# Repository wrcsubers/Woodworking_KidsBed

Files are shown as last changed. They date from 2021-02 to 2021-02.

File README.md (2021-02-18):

# Woodworking Stuff: Kid's Bed Frame

This is a simple Twin sized bed frame made from dimensional lumber.  This bed frame is designed to be modular so it can be easily transformed into a bunk bed by using taller posts.  

Image of Completed Kids Bed Frame 1

Image of Completed Kids Bed Frame 2

Image of Completed Kids Bed Frame 3

I used an 8" Memory Foam mattress, and I wouldn't recommend anything taller than that as you lose side-rail height.  The height of the side rail is set at 12" to allow ample storage beneath the bed, my 2-1/2 year old son had no problem climbing in/out of bed himself at this height.

CAD Files are provided [here](https://github.com/wrcsubers/Woodworking_KidsBedFrame/tree/main/_CAD%20Files) if you want to change anything, or you can print the PDFs directly from [here](https://github.com/wrcsubers/Woodworking_KidsBedFrame/tree/main/_PDFs) =)

* Lumber sizes used:
  * (10) 2" x 2" x 96"
    * Vertical bars for headboard/footboard
    * Vertical and Horizontal bars for side rails
    * Support rails for slats
  * (1) 2" x 4" x 96"
    * Top rail for headboard/footboard
  * (3) 2" x 6" x 96"
    * Bottom rail for headboard/footboard and side rails
  * (2) 4" x 4" x 96"
    * Posts
  * (5) 1" x 3" x 96"
    * Bed slats

* Fasteners used:
  * (20) SPAX 1/4" x 4-1/2" Powerlag Hex Drive Washer Head Zinc Coated Lag Screw
  * 2" Wood Screws
  * 1-1/4" 18ga Brad Nails
  * Wood Glue

**This bed does not conform to the recommended sizes for bar spacing for toddlers/infants!  I felt comfortable using the sizes as specified, please determine on your own if these are suitable for you situation.**

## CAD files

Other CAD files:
_CAD Files/KidsBedFrame_SlatSpacingRail.dxf
_CAD Files/KidsBedFrame_HeadboardFootboard.dxf
_CAD Files/KidsBedFrame_RearSideRail.dxf
_CAD Files/KidsBedFrame_FrontSideRail.dxf

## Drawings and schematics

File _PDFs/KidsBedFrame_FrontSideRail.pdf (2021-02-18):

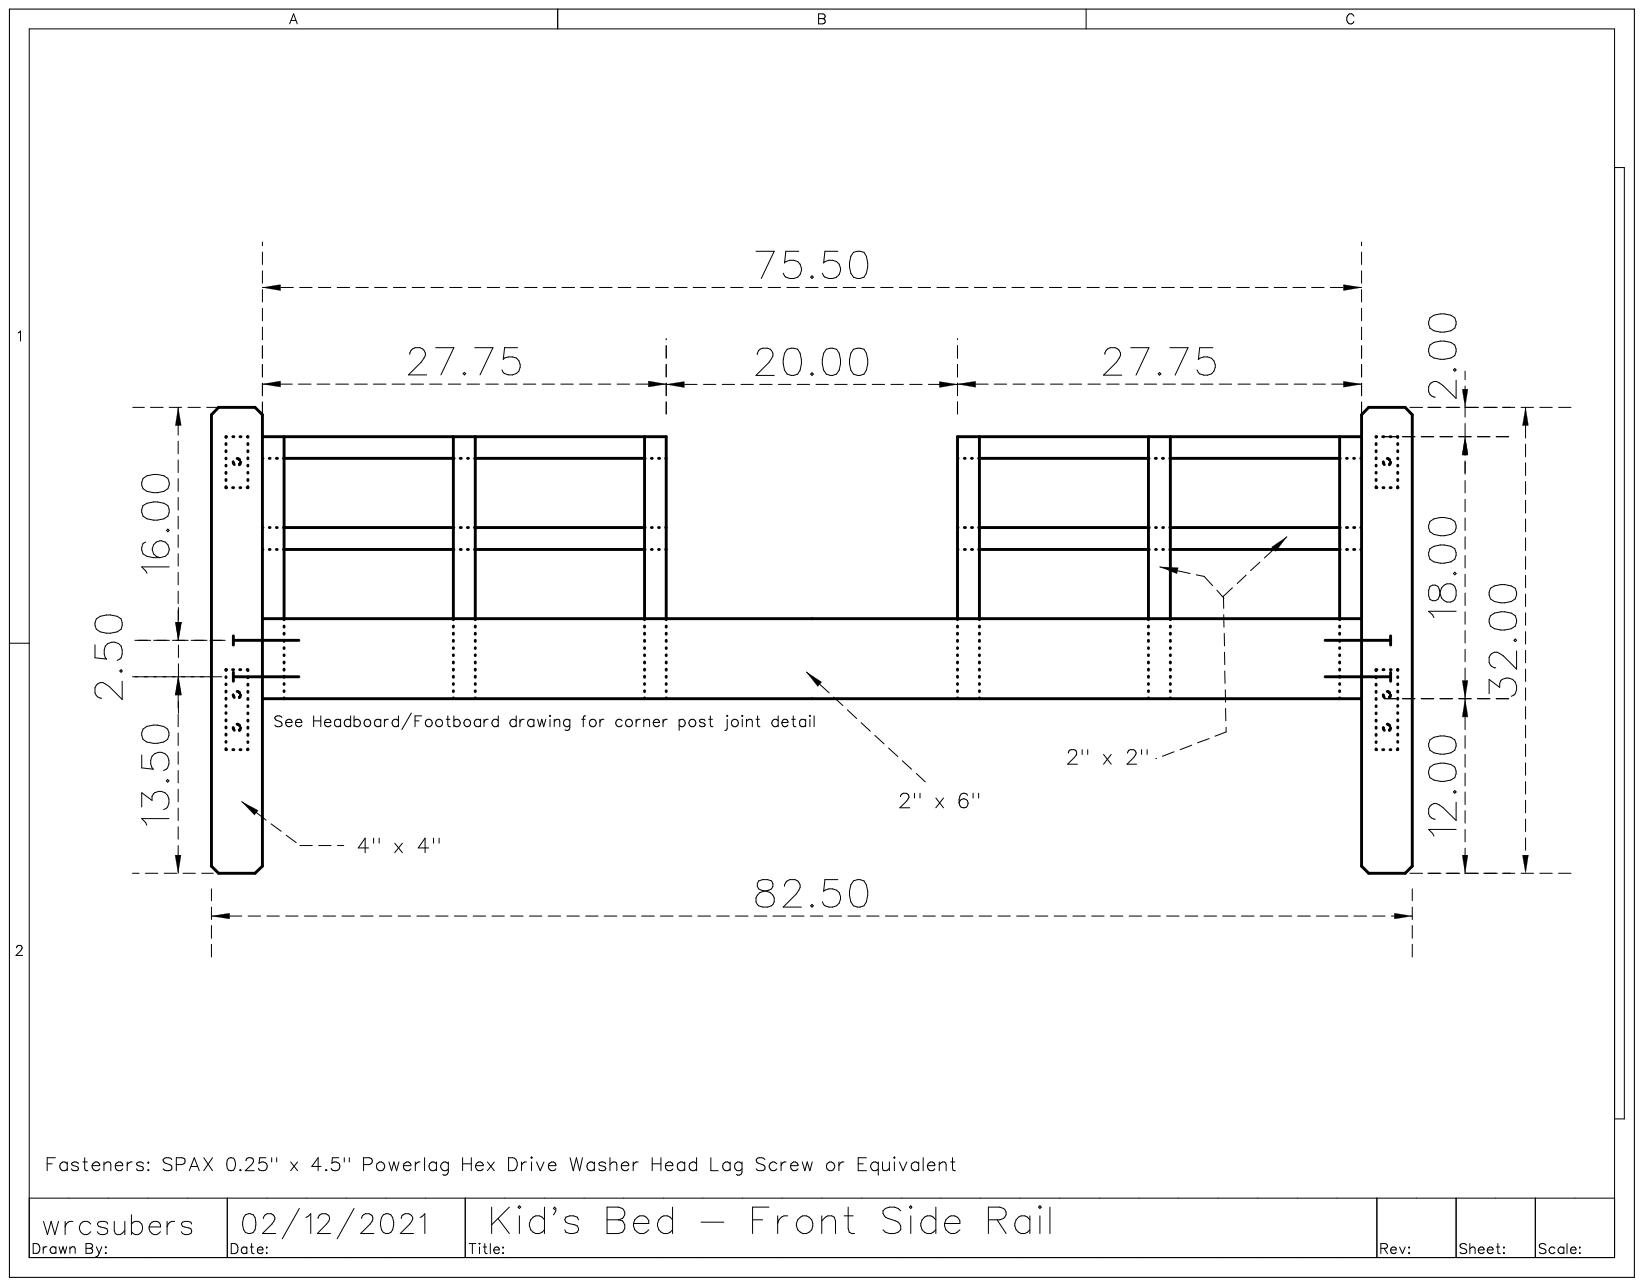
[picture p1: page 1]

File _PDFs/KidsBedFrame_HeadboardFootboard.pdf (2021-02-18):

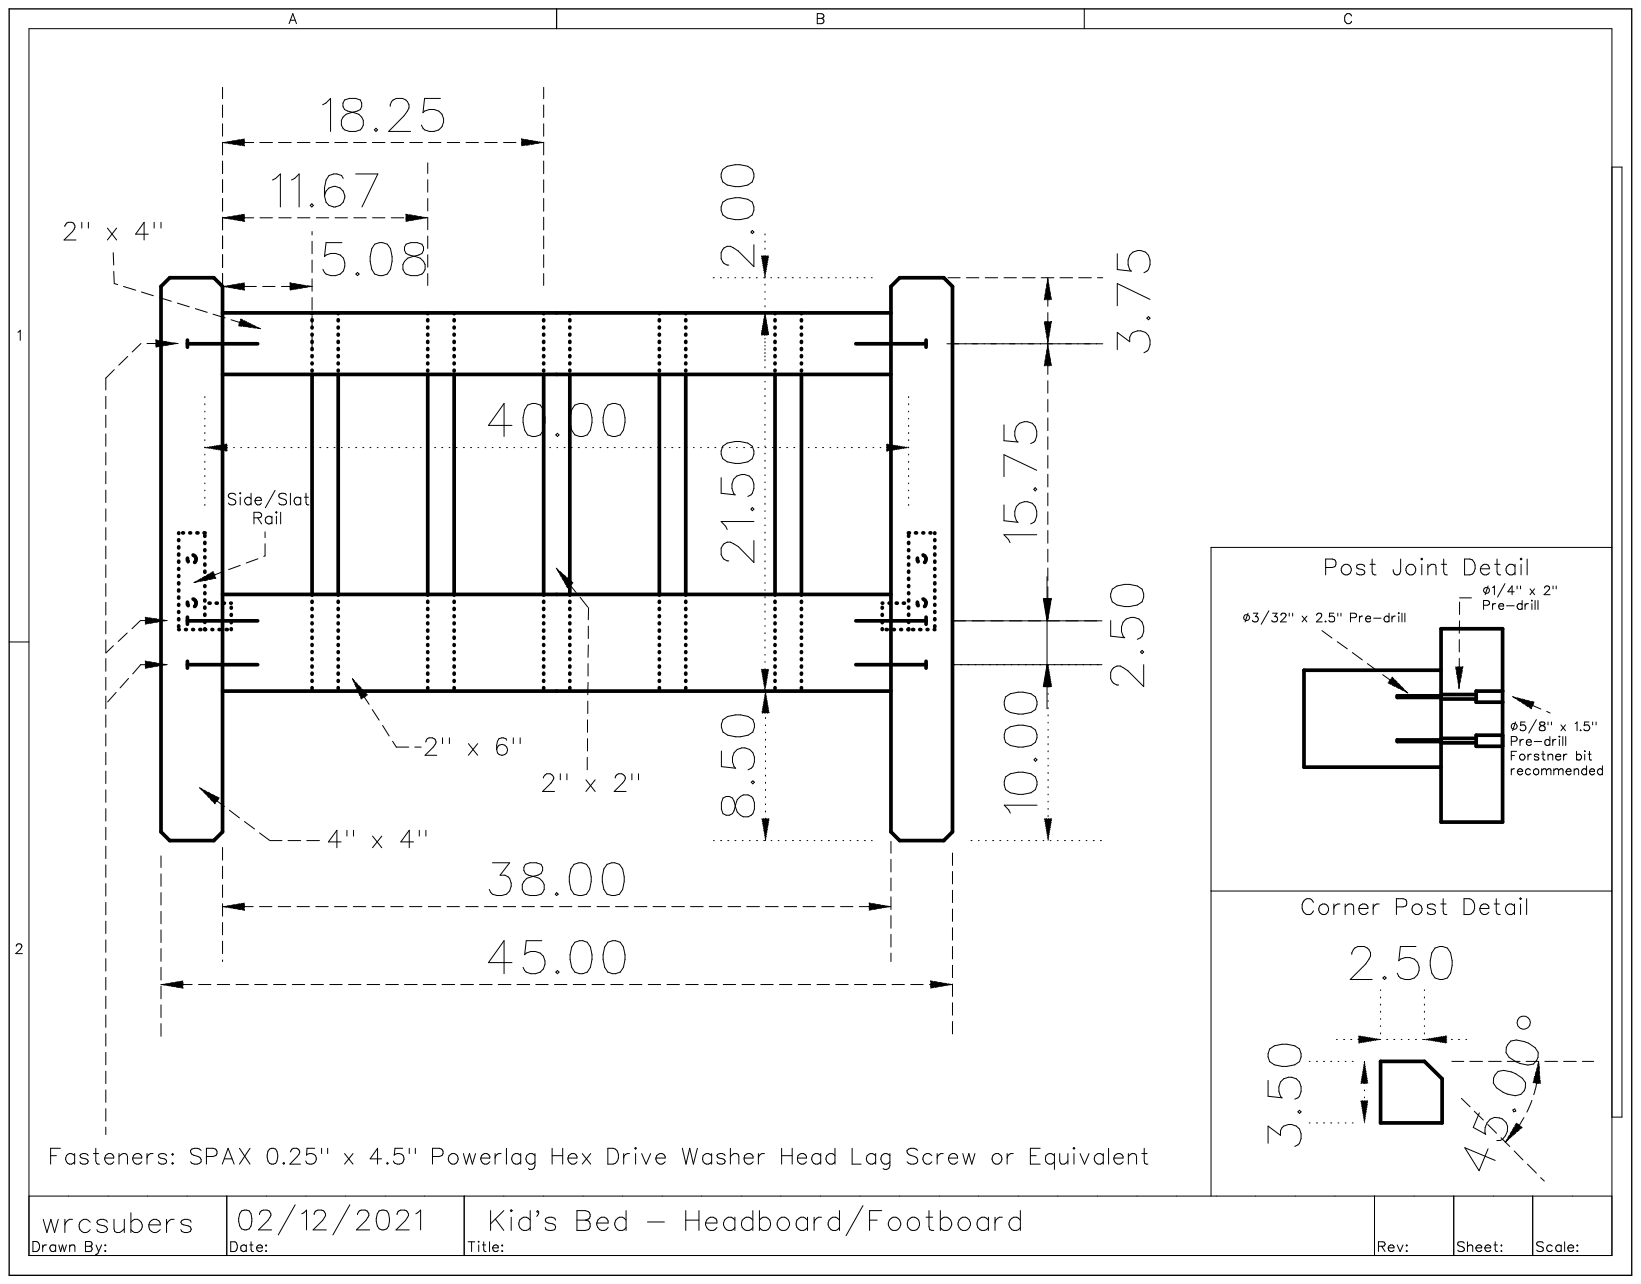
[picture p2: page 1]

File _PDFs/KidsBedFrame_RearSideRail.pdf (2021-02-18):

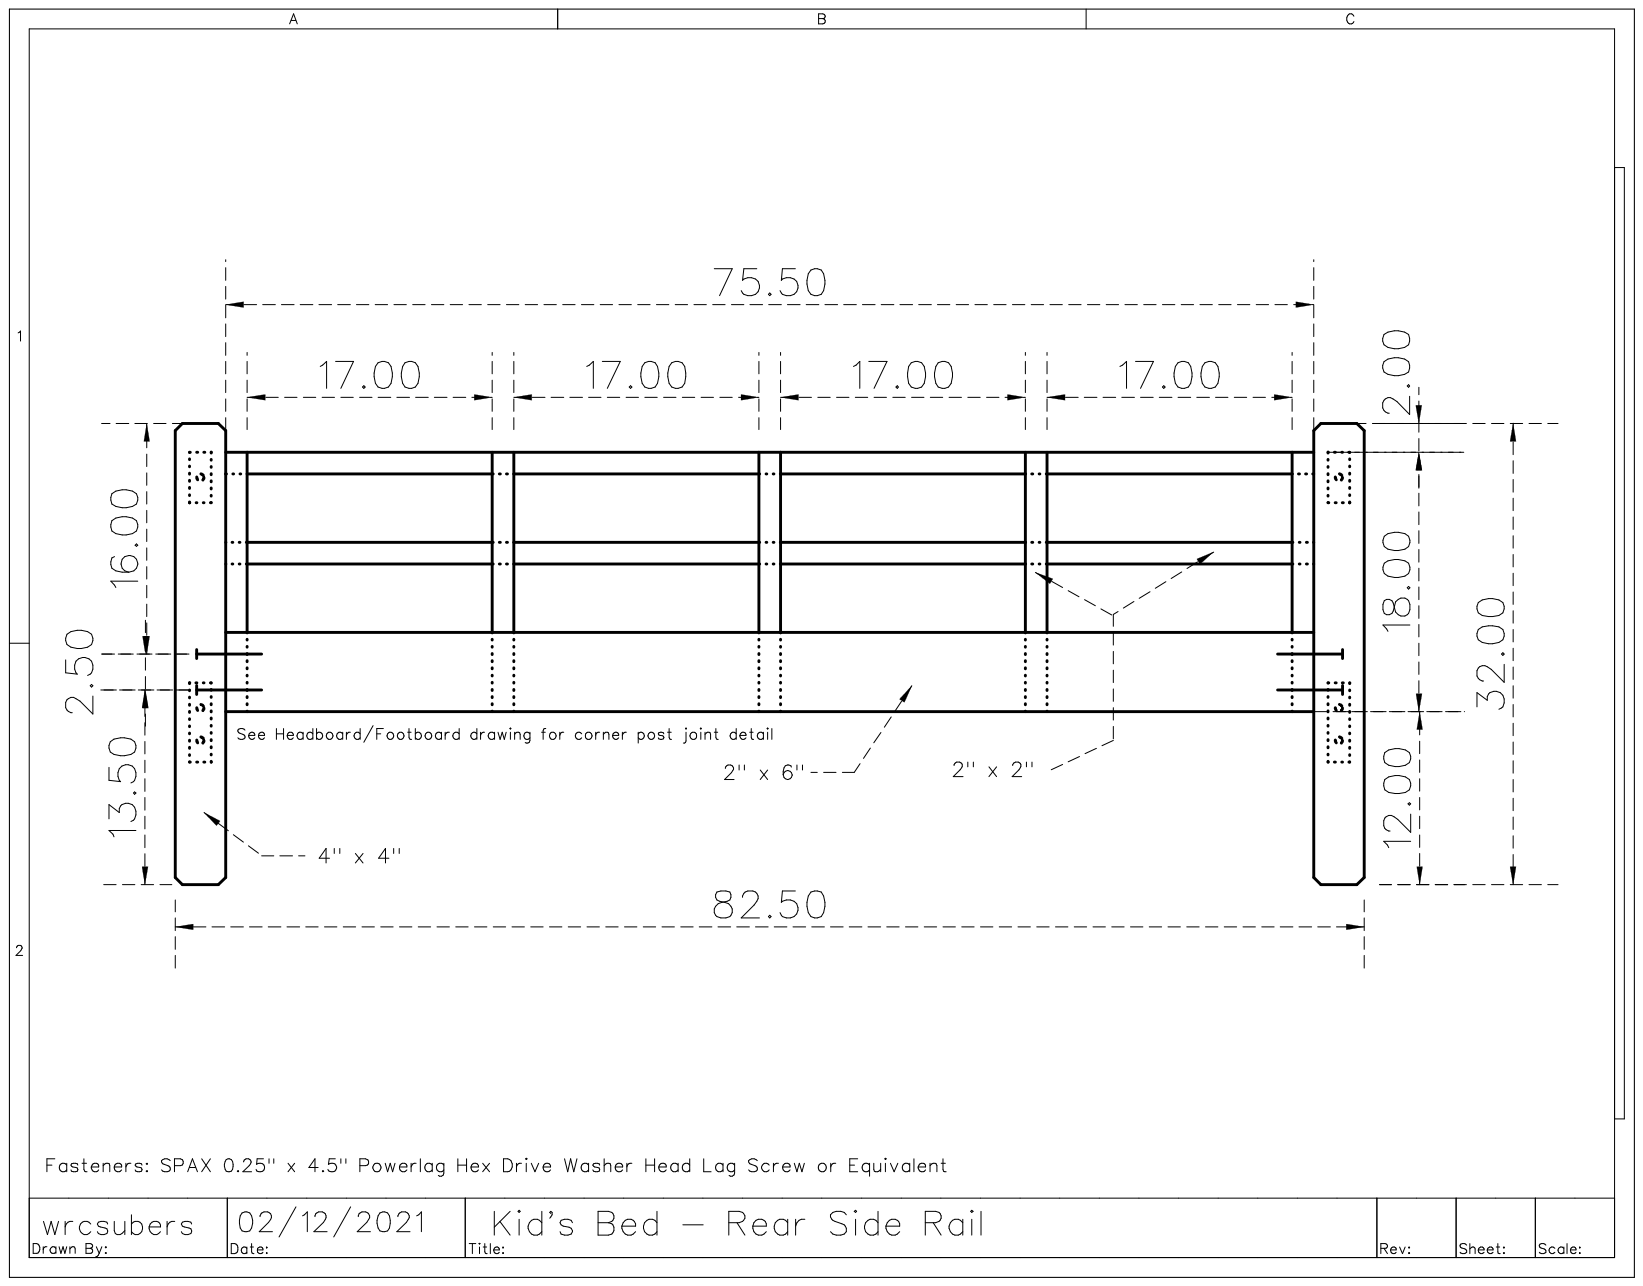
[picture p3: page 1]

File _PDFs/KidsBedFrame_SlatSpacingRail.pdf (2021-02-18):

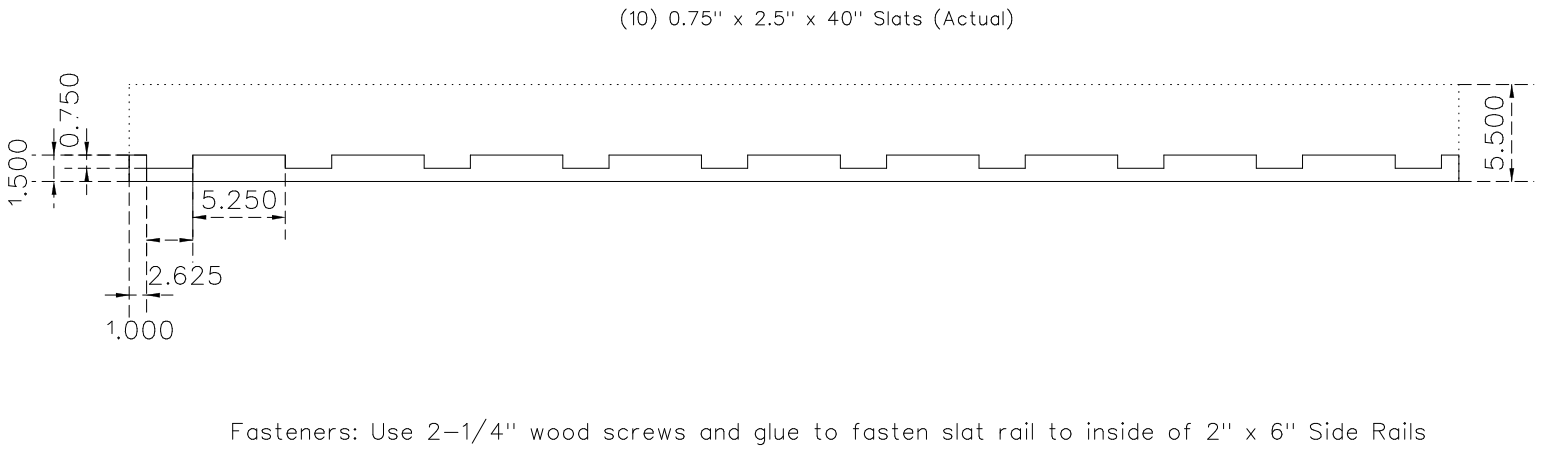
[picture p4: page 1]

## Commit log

2021-02-18 Upload CAD/PDFs/Images
    [KidsBedFrame_FrontSideRail.dxf, KidsBedFrame_HeadboardFootboard.dxf, KidsBedFrame_RearSideRail.dxf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]
2021-02-18 Organize Files
    [KidsBedFrame_FrontSideRail.dxf, KidsBedFrame_HeadboardFootboard.dxf, KidsBedFrame_RearSideRail.dxf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]
2021-02-18 Added Links to CAD Files/PDFs
